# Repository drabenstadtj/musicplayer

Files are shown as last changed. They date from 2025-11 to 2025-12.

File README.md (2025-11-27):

# Raspberry Pi Portable Music Player

A portable music player built with Raspberry Pi Zero 2W that streams from Navidrome server with a 2.2" TFT display and I2S audio output.

## Hardware Components

- **Raspberry Pi Zero 2W** - Main computer
- **Adafruit PiTFT 2.2" HAT (320x240, no touch)** [ID:2315] - Display
- **Adafruit I2S Stereo Decoder - UDA1334A** [ID:3678] - DAC for audio output
- **PowerBoost 1000 Charger** [ID:2465] - Battery management and 5V boost
- **Lithium Ion Polymer Battery 3.7v 2500mAh** [ID:328] - Power source
- **Stacking Header 2x20 Extra Tall** [ID:1979] - For connecting HAT and components
- **Brass M2.5 Standoffs** [ID:2336] - Mounting hardware
- **4 tactile buttons** - User input (GPIO 17, 22, 23, 27)

## Hardware Connections

### I2S DAC (UDA1334A)
```
VIN  → 3.3V (pin 1)
GND  → Ground (pin 6)
WSEL → GPIO 19 (pin 35, I2S Frame Sync)
DIN  → GPIO 21 (pin 40, I2S Data)
BCLK → GPIO 18 (pin 12, I2S Bit Clock)
```

### PiTFT 2.2" Display
- Mounts directly on stacking header
- Uses SPI interface (automatically configured)

### PowerBoost 1000C
- Battery → JST connector on PowerBoost
- USB input → Micro USB on PowerBoost (for charging)
- 5V output → Pi GPIO pins 2 or 4 (5V) and pin 6 (GND)
- LBO pin → GPIO 4 (optional, for battery monitoring)

### Buttons (to be implemented)
```
BTN1 (Up)     → GPIO 17
BTN2 (Down)   → GPIO 22
BTN3 (Select) → GPIO 23
BTN4 (Back)   → GPIO 27
```

## Software Architecture

```
musicplayer/
├── main.py              # Entry point, curses setup
├── config.py            # Configuration (reads from .env)
├── .env                 # Credentials (NOT in git)
├── ui/
│   ├── screens.py       # Screen classes (Menu, Browser, NowPlaying)
│   ├── widgets.py       # Reusable UI components
│   └── theme.py         # Colors, fonts, layout constants
├── player/
│   ├── navidrome.py     # Navidrome API client
│   ├── audio.py         # Audio playback (pygame)
│   └── queue.py         # Playback queue (to be implemented)
├── hardware/
│   ├── buttons.py       # GPIO button handling (to be implemented)
│   └── battery.py       # Battery monitoring (to be implemented)
└── setup/
    ├── config_backups/  # Hardware config backups
    ├── restore_configs.sh
    ├── SETUP.md         # Detailed setup instructions
    └── REIMAGING_CHECKLIST.md
```

## Installation

### Quick Start (Pre-configured SD Card)

1. **Clone repository:**
   ```bash
   git clone git@github.com:YOUR_USERNAME/musicplayer.git
   cd musicplayer
   ```

2. **Restore hardware configuration:**
   ```bash
   sudo ./setup/restore_configs.sh
   sudo reboot
   ```

3. **Install dependencies:**
   ```bash
   python3 -m venv env --system-site-packages
   source env/bin/activate
   pip install -r requirements.txt
   ```

4. **Configure credentials:**
   ```bash
   cp .env.example .env
   nano .env
   # Add your Navidrome server URL, username, and password
   ```

5. **Run:**
   ```bash
   python main.py
   ```

### Fresh Installation (See setup/SETUP.md)

For complete step-by-step instructions on setting up from a fresh Raspberry Pi OS Lite image, see [setup/SETUP.md](setup/SETUP.md).

## Hardware Configuration Files

### `/boot/firmware/config.txt`
```bash
# I2S DAC
dtparam=audio=off
dtoverlay=hifiberry-dac

# PiTFT 2.2" Display
dtoverlay=pitft22,rotate=270,speed=64000000,fps=30
```

### `/boot/firmware/cmdline.txt`
Add to end of line:
```
fbcon=map:10 fbcon=font:VGA8x8
```

### `/etc/asound.conf`
ALSA configuration to route audio to I2S DAC (card 1). See `setup/config_backups/asound.conf`.

## Usage

### Current Features (Phase 3)
- ✅ Browse albums from Navidrome server
- ✅ Stream and play music through I2S DAC
- ✅ Volume control (↑/↓ arrows)
- ✅ Pause/play (Spacebar)
- ✅ Navigation with keyboard

### Keyboard Controls
```
Main Menu:
  ↑/↓        - Navigate menu
  ENTER      - Select option
  Q          - Quit

Album Browser:
  ↑/↓        - Navigate lists
  ENTER      - Select album / Play song
  BACKSPACE  - Go back
  Q          - Quit

Now Playing:
  SPACE      - Play / Pause
  ↑/↓        - Volume up / down
  BACKSPACE  - Return to browser
  Q          - Quit
```

## Planned Features (Future Phases)

### Phase 4: Hardware Integration
- [ ] GPIO button support (replace keyboard)
- [ ] Battery level monitoring
- [ ] Power management

### Phase 5: Advanced Features
- [ ] Playlist support
- [ ] Queue management
- [ ] Shuffle/repeat modes
- [ ] Album art display
- [ ] Settings menu

### Phase 6: Polish
- [ ] Auto-start on boot
- [ ] Sleep timer
- [ ] Display timeout/dimming
- [ ] Safe shutdown on low battery

## Development

### Requirements
- Python 3.9+
- pygame
- requests
- python-dotenv

### Environment Variables (.env)
```bash
NAVIDROME_URL=https://your-server.com
NAVIDROME_USER=username
NAVIDROME_PASS=password
```

### Testing Audio
```bash
# Test I2S DAC
speaker-test -c2 -t wav

# Check audio devices
aplay -l

# Should show:
# card 1: sndrpihifiberry [snd_rpi_hifiberry_dac]
```

### Testing Display
```bash
# Display should show console after boot
# Run music player to see ncurses interface
python main.py
```

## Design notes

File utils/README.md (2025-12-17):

# Music Player Logging System

This directory contains the centralized logging system for the Music Player application.

## Log Files

All logs are stored in `/tmp/musicplayer_logs/`:

- **musicplayer.log** - Main application logs (navigation, user actions)
- **audio.log** - Audio playback logs (VLC, PulseAudio, streaming details) [DEBUG level]
- **ui.log** - UI rendering and screen updates
- **hardware.log** - Button events and GPIO interactions
- **network.log** - Network requests to Navidrome server [DEBUG level]

## Log Rotation

Logs automatically rotate when they reach 5MB, keeping 3 backup files:
- `musicplayer.log` (current)
- `musicplayer.log.1` (previous)
- `musicplayer.log.2` (older)
- `musicplayer.log.3` (oldest)

## Usage

```python
from utils.logger import get_logger

logger = get_logger("main")  # or "audio", "ui", "hardware", "network"

logger.debug("Detailed debugging information")
logger.info("General information")
logger.warning("Warning messages")
logger.error("Error messages")
logger.exception("Error with full stack trace")
```

## Log Levels

- **DEBUG**: Detailed diagnostic information (VLC states, UI updates)
- **INFO**: General informational messages (navigation, playback events)
- **WARNING**: Warning messages (missing features, fallback behavior)
- **ERROR**: Error messages with stack traces

## Viewing Logs

On the Raspberry Pi:
```bash
# View real-time logs
tail -f /tmp/musicplayer_logs/musicplayer.log
tail -f /tmp/musicplayer_logs/audio.log

# View all logs
cat /tmp/musicplayer_logs/musicplayer.log

# Search logs
grep "ERROR" /tmp/musicplayer_logs/*.log
```

## Log Format

```
YYYY-MM-DD HH:MM:SS | logger_name | LEVEL | message
```

Example:
```
2025-01-15 14:23:45 | audio | INFO | ✓ VLC is now playing!
2025-01-15 14:23:46 | main | INFO | Navigating to Albums
```

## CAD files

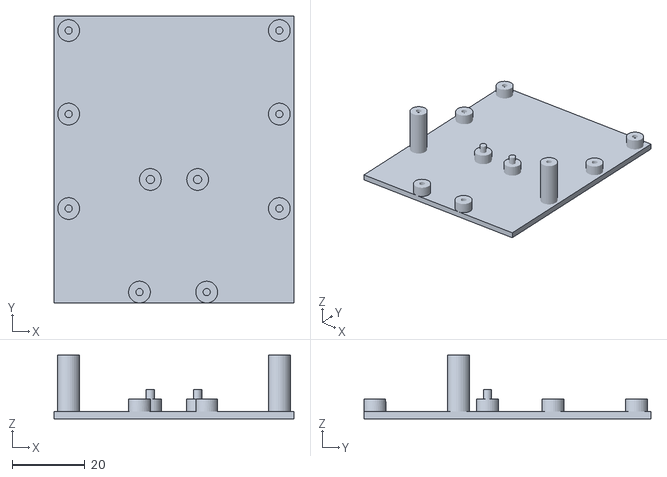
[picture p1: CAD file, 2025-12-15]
case/pi case v1.stl
66.0 x 79.0 x 17.5

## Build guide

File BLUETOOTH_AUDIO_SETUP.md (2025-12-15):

# Bluetooth-Only Audio Setup for Raspberry Pi

This guide configures your Raspberry Pi to use Bluetooth headphones as the only audio output (no sound card required).

## Prerequisites

```bash
# Update system
sudo apt-get update
sudo apt-get upgrade

# Install required packages
sudo apt-get install -y bluetooth bluez pulseaudio pulseaudio-module-bluetooth

# Install Python requirements
pip3 install -r requirements.txt
```

## PulseAudio Configuration

### 1. Enable PulseAudio for your user

```bash
# Start PulseAudio
pulseaudio --start

# Make it start automatically
systemctl --user enable pulseaudio
```

### 2. Configure PulseAudio for Bluetooth

Edit `/etc/pulse/default.pa` and ensure these lines are present:

```
# Bluetooth support
load-module module-bluetooth-policy
load-module module-bluetooth-discover
```

### 3. Restart PulseAudio

```bash
pulseaudio -k
pulseaudio --start
```

## Bluetooth Setup

### 1. Enable Bluetooth service

```bash
sudo systemctl enable bluetooth
sudo systemctl start bluetooth
```

### 2. Check Bluetooth is working

```bash
bluetoothctl
# Inside bluetoothctl:
power on
agent on
default-agent
scan on
# Wait for your headphones to appear, then:
scan off
exit
```

## Troubleshooting

### No audio output / ALSA errors

If you see ALSA errors like:
```
ALSA lib confmisc.c:855:(parse_card) cannot find card '0'
ALSA lib pcm.c:2722:(snd_pcm_open_noupdate) Unknown PCM default
```

This is normal when you don't have a sound card. The app now uses PulseAudio instead.

To verify PulseAudio is working:

```bash
# Check PulseAudio status
pulseaudio --check
echo $?  # Should return 0 if running

# List audio sinks (should show Bluetooth when connected)
pactl list short sinks

# Test audio (should work after connecting Bluetooth)
paplay /usr/share/sounds/alsa/Front_Center.wav
```

### Bluetooth scan finds 0 devices

1. **Make sure Bluetooth is enabled:**
   ```bash
   sudo systemctl status bluetooth
   # Should show "active (running)"
   ```

2. **Put your headphones in pairing mode:**
   - Most headphones require holding the power button for 5-10 seconds
   - Look for a flashing LED (usually blue/red alternating)

3. **Check permissions:**
   ```bash
   # Your user should be in the bluetooth group
   sudo usermod -a -G bluetooth $USER
   # Log out and back in for group change to take effect
   ```

4. **Manual scan test:**
   ```bash
   bluetoothctl
   power on
   scan on
   # Wait 10 seconds - you should see devices appear
   ```

5. **Check Bluetooth hardware:**
   ```bash
   hciconfig
   # Should show hci0 UP RUNNING

   # If not UP:
   sudo hciconfig hci0 up
   ```

### Connected but no audio

1. **Ensure Bluetooth is set as default sink:**
   ```bash
   # List sinks
   pactl list short sinks

   # Look for bluez_sink.XX_XX_XX_XX_XX_XX
   # Set as default (replace with your actual sink name):
   pactl set-default-sink bluez_sink.XX_XX_XX_XX_XX_XX.a2dp_sink
   ```

2. **Check audio routing:**
   ```bash
   # See active audio streams
   pactl list sink-inputs

   # Move to Bluetooth (replace IDs with actual values):
   pactl move-sink-input <INPUT_ID> bluez_sink.XX_XX_XX_XX_XX_XX.a2dp_sink
   ```

3. **Verify codec:**
   ```bash
   # Check Bluetooth audio profile
   pactl list cards
   # Look for "Active Profile: a2dp_sink" (high quality)
   # If showing "headset_head_unit" (low quality), change it:
   pactl set-card-profile bluez_card.XX_XX_XX_XX_XX_XX a2dp_sink
   ```

### App still shows "No audio available"

This means pygame couldn't initialize with PulseAudio. Check:

```bash
# Make sure PulseAudio is running
pulseaudio --check && echo "Running" || echo "Not running"

# Check if SDL can see PulseAudio
SDL_AUDIODRIVER=pulseaudio python3 -c "import pygame; pygame.mixer.init(); print('OK')"
```

If this fails, try:

```bash
# Restart PulseAudio
pulseaudio -k
pulseaudio --start

# Try the app again
python3 main.py
```

## Using the Music Player

Once Bluetooth is set up:

1. **Start the app:**
   ```bash
   cd ~/musicplayer  # or wherever you installed it
   python3 main.py
   ```

2. **Connect headphones:**
   - Navigate to Settings → Bluetooth Audio
   - Press SELECT on "Scan for devices"
   - Wait for scan to complete
   - Navigate to your headphones
   - Press SELECT to connect

3. **The app will automatically:**
   - Pair with the device (if needed)
   - Connect to it
   - Set it as the default audio sink
   - Route all music to your headphones

4. **Auto-reconnect:**
   - Once connected, the device is trusted
   - It will auto-reconnect when powered on in range

## PulseAudio + Bluetooth Architecture

```
┌─────────────────┐
│  Music Player   │
│   (pygame)      │
└────────┬────────┘
         │
         │ SDL_AUDIODRIVER=pulseaudio
         ▼
┌─────────────────┐
│  PulseAudio     │
│   (sound server)│
└────────┬────────┘
         │
         │ module-bluetooth-discover
         ▼
┌─────────────────┐
│  BlueZ          │
│   (Bluetooth)   │
└────────┬────────┘
         │
         │ A2DP profile
         ▼
┌─────────────────┐
│  Headphones     │
└─────────────────┘
```

The app bypasses ALSA entirely by:
1. Setting `SDL_AUDIODRIVER=pulseaudio` in [player/audio.py](player/audio.py:10)
2. PulseAudio handles all audio routing
3. When Bluetooth device connects, PulseAudio creates a `bluez_sink`
4. The app's BluetoothManager sets this as the default sink
5. All pygame audio automatically routes to Bluetooth

## Performance Tips

For best audio quality on Bluetooth:

1. **Disable WiFi power saving (can interfere with Bluetooth):**
   ```bash
   sudo iwconfig wlan0 power off
   ```

2. **Increase Bluetooth priority:**
   ```bash
   sudo nice -n -10 bluetoothd
   ```

3. **Use A2DP profile (not HSP/HFP):**
   - A2DP = high quality stereo
   - HSP/HFP = phone headset (mono, low quality)
   - The app automatically uses A2DP

4. **If you get choppy audio or static:**

   Edit `/etc/pulse/daemon.conf` and uncomment/set these values:
   ```
   default-fragment-size-msec = 25
   resample-method = soxr-vhq
   ```

   Then restart PulseAudio:
   ```bash
   pulseaudio -k
   pulseaudio --start
   ```

5. **Check WiFi interference:**
   - Both WiFi and Bluetooth use 2.4GHz band
   - If possible, use 5GHz WiFi or ethernet
   - Or disable WiFi: `sudo ifconfig wlan0 down`

## Common Issues

| Problem | Solution |
|---|---|
| Choppy audio / static | VLC buffer settings in [player/audio.py](player/audio.py:22), or tune PulseAudio (see Performance Tips #4) |
| Connection drops | Move Pi closer to headphones, reduce WiFi interference |
| Scan finds 0 devices | Headphones in pairing mode? Bluetooth service running? |
| No audio | Check PulseAudio running, Bluetooth connected, default sink set |
| ALSA errors | Normal - app uses PulseAudio not ALSA |

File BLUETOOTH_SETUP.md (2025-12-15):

# Bluetooth Audio Setup Guide

This guide explains how to use the Bluetooth settings screen to connect your Raspberry Pi to Bluetooth headphones.

## Prerequisites

On your Raspberry Pi, make sure you have the required packages:

```bash
sudo apt-get update
sudo apt-get install bluetooth bluez pulseaudio pulseaudio-module-bluetooth
```

## Using the Bluetooth Settings Screen

1. **Navigate to Settings**
   - From the main menu, select "Settings"
   - The Bluetooth Audio screen will open

2. **Scan for Devices**
   - Press `S` to scan for nearby Bluetooth devices
   - Scanning takes about 5 seconds
   - Your headphones should appear in the list

3. **Connect to Headphones**
   - Use ↑/↓ to navigate to your headphones
   - Press `ENTER` to connect
   - The app will:
     - Pair with the device (if not already paired)
     - Connect to the device
     - Set it as the default audio output
     - Trust the device for auto-reconnect

4. **Check Connection Status**
   - Connected devices show `[CONNECTED]` in green
   - Paired devices show `[PAIRED]` in yellow
   - The current connection is shown at the top

5. **Disconnect**
   - Press `D` to disconnect from the current device

## Keyboard Controls

- **↑/↓**: Navigate device list
- **ENTER**: Connect to selected device
- **S**: Scan for new devices
- **D**: Disconnect current device
- **BACKSPACE**: Return to main menu
- **Q**: Quit application

## Physical Button Controls

If using the hardware buttons:
- **UP/DOWN**: Navigate device list
- **SELECT**: Connect to selected device
- **BACK**: Return to main menu

## Troubleshooting

### Headphones not appearing
1. Make sure your headphones are in pairing mode
2. Press `S` to scan again
3. Make sure Bluetooth is enabled on the Pi: `sudo systemctl status bluetooth`

### Connection fails
1. Remove the device: Use `bluetoothctl` manually to remove
2. Restart Bluetooth service: `sudo systemctl restart bluetooth`
3. Try pairing again

### Audio still plays through Pi's output
The app automatically sets the Bluetooth device as the default audio sink. If this doesn't work:

```bash
# List audio sinks
pactl list short sinks

# Find the bluez sink and set as default
pactl set-default-sink bluez_sink.XX_XX_XX_XX_XX_XX.a2dp_sink
```

### Check audio routing
```bash
# See what's playing
pactl list sink-inputs

# Move audio to Bluetooth
pactl move-sink-input <input-id> bluez_sink.XX_XX_XX_XX_XX_XX.a2dp_sink
```

## Auto-reconnect

Once you've connected to a device, it's automatically trusted for auto-reconnect. Your headphones should reconnect automatically when:
- They're powered on
- They're in range
- Bluetooth is enabled on the Pi

## Technical Details

The Bluetooth manager uses:
- **bluetoothctl**: For device pairing and connection
- **PulseAudio (pactl)**: For audio routing

All audio played through pygame will automatically route to the connected Bluetooth device.

## Removing DAC Code

Since you removed the DAC hardware, the app now uses:
1. **Built-in audio** (if no Bluetooth connected)
2. **Bluetooth audio** (when connected via Settings)

The mock audio player is used if pygame can't initialize audio (like in WSL for development).

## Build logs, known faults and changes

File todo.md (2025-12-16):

TODO:
- cache album metadata from navidrome
- add album art display
- fix settings screen
- change scrolling to scroll album and artist together
- make arrows keep moving when holding down
- tune choppiness of playback
- fix volume control
- make album browser and album songlist separate screens
- make a way to get back to now playing screen (maybe button 1 and button 4 simultaneously)
- remove battery icon from now playing screen

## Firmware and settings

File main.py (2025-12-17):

import curses
from player.navidrome import NavidromeClient
from ui.screens import (MainMenuScreen, AlbumBrowserScreen, SongListScreen, NowPlayingScreen,
                        BluetoothSettingsScreen, ArtistBrowserScreen, PlaylistBrowserScreen)
from ui.theme import init_colors
from hardware.button_controller import ButtonController
from utils.logger import get_logger, log_startup, log_shutdown

logger = get_logger("main")

class MusicPlayerApp:
    def __init__(self, stdscr):
        logger.info("Initializing MusicPlayerApp")
        self.stdscr = stdscr

        # Try to connect to Navidrome
        logger.info("Connecting to Navidrome client")
        self.client = NavidromeClient()

        # Try to initialize audio player, fall back to mock if no audio device
        try:
            logger.info("Initializing audio player")
            from player.audio import AudioPlayer
            self.audio = AudioPlayer()
        except Exception as e:
            logger.warning(f"Failed to initialize audio player, using mock: {e}")
            from player.audio_mock import AudioPlayer
            self.audio = AudioPlayer()

        # Setup curses
        logger.debug("Setting up curses interface")
        curses.curs_set(0)
        self.stdscr.nodelay(1)
        self.stdscr.timeout(100)
        init_colors()

        self.current_screen = None
        self.running = True

        # Cache for metadata
        self.cached_albums = None
        self.cached_artists = None
        self.cached_playlists = None

        # Track if now playing screen is available
        self.has_active_playback = False
        self.should_return_to_now_playing = False

        # Initialize button controller
        logger.info("Initializing button controller")
        self.button_controller = ButtonController(self, use_gpio=True)
        self.button_controller.start()
        logger.info("MusicPlayerApp initialization complete")
    
    def run(self):
        logger.info("Starting main application loop")
        # Test Navidrome connection
        if not self.client.test_connection():
            logger.error("Failed to connect to Navidrome server")
            self.stdscr.clear()
            self.stdscr.addstr(0, 0, "Failed to connect to Navidrome server!")
            self.stdscr.addstr(1, 0, "Press any key to exit...")
            self.stdscr.refresh()
            self.stdscr.getch()
            return

        logger.info("Navidrome connection successful")
        # Start with main menu
        try:
            while self.running:
                menu = MainMenuScreen(self.stdscr)
                self.current_screen = menu
                menu.draw()
                
                while self.running:
                    key = self.stdscr.getch()

                    result = None

                    if key != -1:
                        # Try button emulator first, only call handle_input if not handled
                        handled_by_buttons = self._handle_keyboard_input(key)
                        if not handled_by_buttons:
                            result = menu.handle_input(key)
                    
                    # Check for button actions
                    if hasattr(menu, '_pending_action') and menu._pending_action:
                        result = menu._pending_action
                        menu._pending_action = None
                    
                    if result == False:
                        logger.info("User quit from main menu")
                        self.running = False
                        break
                    elif result == "Albums":
                        logger.info("Navigating to Albums")
                        self.show_albums()
                        break
                    elif result == "Artists":
                        logger.info("Navigating to Artists")
                        self.show_artists()
                        break
                    elif result == "Playlists":
                        logger.info("Navigating to Playlists")
                        self.show_playlists()
                        break
                    elif result == "Settings":
                        logger.info("Navigating to Settings")
                        self.show_settings()
                        break
                    elif result:
                        menu.draw()
        finally:
            logger.info("Application shutting down")
            self.cleanup()
    
    def _handle_keyboard_input(self, key):
        """Handle keyboard input via button emulator

        Returns:
            True if key was handled by button emulator, False otherwise
        """
        from hardware.buttons import KeyboardButtonEmulator

        if isinstance(self.button_controller.handler, KeyboardButtonEmulator):
            key_map = {
                curses.KEY_UP: 'KEY_UP',
                curses.KEY_DOWN: 'KEY_DOWN',
                curses.KEY_BACKSPACE: 'KEY_BACKSPACE',
                127: 'KEY_BACKSPACE',
                10: '\n',
            }

            mapped_key = key_map.get(key)
            if mapped_key:
                self.button_controller.handler.handle_key(mapped_key)
                return True
        return False
    
    def show_albums(self):
        # Use cached albums if available, otherwise fetch from Navidrome
        if self.cached_albums is None:
            logger.info("Fetching albums from Navidrome")
            albums = self.client.get_all_albums()
            self.cached_albums = albums
            logger.info(f"Cached {len(albums)} albums")
        else:
            logger.debug("Using cached albums")
            albums = self.cached_albums

        if not albums:
            logger.warning("No albums found")
            return

        browser = AlbumBrowserScreen(self.stdscr, albums)
        self.current_screen = browser
        browser.draw()

        while self.running:
            # Check for now playing combo
            if self.should_return_to_now_playing:
                self.should_return_to_now_playing = False
                self.show_now_playing()
                # Restore current_screen to browser after returning
                self.current_screen = browser
                browser.draw()
                continue

            key = self.stdscr.getch()

            result = None

            if key != -1:
                # Try button emulator first, only call handle_input if not handled
                handled_by_buttons = self._handle_keyboard_input(key)
                if not handled_by_buttons:
                    result = browser.handle_input(key)

            # Check for button actions
            if hasattr(browser, '_pending_action') and browser._pending_action:
                result = browser._pending_action
                browser._pending_action = None

            if result == False or result == "back":
                logger.info("Returning to main menu from albums")
                break
            elif isinstance(result, tuple):
                action, data = result
                if action == "select_album":
                    logger.info(f"Album selected: {data.get('name', 'Unknown')}")
                    # Show song list screen (this will return when user presses back)
                    self.show_song_list(data)
                    # Restore current_screen to browser after returning from song list
                    self.current_screen = browser
                    browser.draw()

            browser.draw()

    def show_song_list(self, album):
        """Show song list for an album"""
        logger.info(f"Loading songs for album: {album.get('name', 'Unknown')}")
        # Load songs from Navidrome
        songs = self.client.get_album_songs(album['id'])

        if not songs:
            logger.warning(f"No songs found for album: {album.get('name', 'Unknown')}")
            return

        logger.info(f"Loaded {len(songs)} songs")

        song_list = SongListScreen(self.stdscr, album, songs)
        self.current_screen = song_list
        song_list.draw()

        while self.running:
            # Check for now playing combo
            if self.should_return_to_now_playing:
                self.should_return_to_now_playing = False
                self.show_now_playing()
                # Restore current_screen to song_list after returning
                self.current_screen = song_list
                song_list.draw()
                continue

            key = self.stdscr.getch()

            result = None

            if key != -1:
                # Try button emulator first, only call handle_input if not handled
                handled_by_buttons = self._handle_keyboard_input(key)
                if not handled_by_buttons:
                    result = song_list.handle_input(key)

            # Check for button actions
            if hasattr(song_list, '_pending_action') and song_list._pending_action:
                result = song_list._pending_action
                song_list._pending_action = None

            if result == False:
                logger.info("Exiting song list (returning to album browser)")
                return  # Return to album browser
            elif result == "back":
                logger.info("Back pressed in song list")
                return  # Return to album browser
            elif isinstance(result, tuple):
                action, data = result
                if action == "play_song":
                    logger.info(f"Playing song: {data.get('title', 'Unknown')}")
                    self.play_song(data)
                    self.show_now_playing()
                    # Restore current_screen to song_list after returning
                    self.current_screen = song_list
                    song_list.draw()

            song_list.draw()

    def play_song(self, song):
        """Start playing a song"""
        logger.info(f"Requesting stream for song: {song.get('title', 'Unknown')} by {song.get('artist', 'Unknown')}")
        stream_url = self.client.get_stream_url(song['id'])
        if stream_url:
            logger.info(f"Stream URL obtained: {stream_url}")
            self.audio.play(stream_url, song)
            self.has_active_playback = True
        else:
            logger.error(f"Failed to get stream URL for song: {song.get('title', 'Unknown')}")

    def show_now_playing(self):
        """Show now playing screen"""
        logger.info("Showing now playing screen")
        now_playing = NowPlayingScreen(self.stdscr, self.audio, self.client)
        self.current_screen = now_playing
        now_playing.draw()

        while self.running:
            key = self.stdscr.getch()

            result = None

            if key != -1:
                # Try button emulator first, only call handle_input if not handled
                handled_by_buttons = self._handle_keyboard_input(key)
                if not handled_by_buttons:
                    result = now_playing.handle_input(key)

            # Check for button actions
            if hasattr(now_playing, '_pending_action') and now_playing._pending_action:
                result = now_playing._pending_action
                now_playing._pending_action = None

            if result == False:
                logger.info("Exiting now playing screen")
                return  # Exit and return to previous screen
            elif result == "back":
                logger.info("Back pressed in now playing screen")
                return  # Exit and return to previous screen

            now_playing.draw()

    def show_settings(self):
        """Show settings menu"""
        logger.info("Showing settings screen")
        bt_settings = BluetoothSettingsScreen(self.stdscr)
        self.current_screen = bt_settings
        bt_settings.draw()

        while self.running:
            # Check for now playing combo
            if self.should_return_to_now_playing:
                self.should_return_to_now_playing = False
                self.show_now_playing()
                # Restore current_screen to bt_settings after returning
                self.current_screen = bt_settings
                bt_settings.draw()
                continue

            key = self.stdscr.getch()

            result = None

            if key != -1:
                # Try button emulator first, only call handle_input if not handled
                handled_by_buttons = self._handle_keyboard_input(key)
                if not handled_by_buttons:
                    result = bt_settings.handle_input(key)

            # Check for button actions
            if hasattr(bt_settings, '_pending_action') and bt_settings._pending_action:
                result = bt_settings._pending_action
                bt_settings._pending_action = None

            if result == False or result == "back":
                logger.info("Exiting settings screen")
                break

            bt_settings.draw()

    def show_artists(self):
        """Show artists browser"""
        # Use cached artists if available, otherwise fetch from Navidrome
        if self.cached_artists is None:
            logger.info("Fetching artists from Navidrome")
            artists = self.client.get_artists()
            self.cached_artists = artists
            logger.info(f"Cached {len(artists)} artists")
        else:
            logger.debug("Using cached artists")
            artists = self.cached_artists

        if not artists:
            logger.warning("No artists found")
            return

        browser = ArtistBrowserScreen(self.stdscr, artists)
        self.current_screen = browser
        browser.draw()

        while self.running:
            # Check for now playing combo
            if self.should_return_to_now_playing:
                self.should_return_to_now_playing = False
                self.show_now_playing()
                self.current_screen = browser
                browser.draw()
                continue

            key = self.stdscr.getch()

            result = None

            if key != -1:
                # Try button emulator first, only call handle_input if not handled
                handled_by_buttons = self._handle_keyboard_input(key)
                if not handled_by_buttons:
                    result = browser.handle_input(key)

            # Check for button actions
            if hasattr(browser, '_pending_action') and browser._pending_action:
                result = browser._pending_action
                browser._pending_action = None

            if result == False or result == "back":
                logger.info("Returning to main menu from artists")
                break
            elif isinstance(result, tuple):
                action, data = result
                if action == "select_artist":
                    logger.info(f"Artist selected: {data.get('name', 'Unknown')}")
                    # Show artist's albums
                    self.show_artist_albums(data)
                    # Restore current_screen to browser after returning
                    self.current_screen = browser
                    browser.draw()

            browser.draw()

    def show_artist_albums(self, artist):
        """Show albums for a specific artist"""
        logger.info(f"Loading albums for artist: {artist.get('name', 'Unknown')}")
        albums = self.client.get_artist_albums(artist['id'])

        if not albums:
            logger.warning(f"No albums found for artist: {artist.get('name', 'Unknown')}")
            return

        logger.info(f"Loaded {len(albums)} albums")

        # Create album browser for this artist's albums
        browser = AlbumBrowserScreen(self.stdscr, albums)
        self.current_screen = browser
        browser.draw()

        while self.running:
            # Check for now playing combo
            if self.should_return_to_now_playing:
                self.should_return_to_now_playing = False
                self.show_now_playing()
                self.current_screen = browser
                browser.draw()
                continue

            key = self.stdscr.getch()

            result = None

            if key != -1:
                # Try button emulator first, only call handle_input if not handled
                handled_by_buttons = self._handle_keyboard_input(key)
                if not handled_by_buttons:
                    result = browser.handle_input(key)

            # Check for button actions
            if hasattr(browser, '_pending_action') and browser._pending_action:
                result = browser._pending_action
                browser._pending_action = None

            if result == False or result == "back":
                logger.info("Returning to artist browser from albums")
                return  # Return to artist browser
            elif isinstance(result, tuple):
                action, data = result
                if action == "select_album":
                    logger.info(f"Album selected: {data.get('name', 'Unknown')}")
                    # Show song list screen
                    self.show_song_list(data)
                    # Restore current_screen to browser after returning from song list
                    self.current_screen = browser
                    browser.draw()

            browser.draw()

    def show_playlists(self):
        """Show playlists browser"""
        # Use cached playlists if available, otherwise fetch from Navidrome
        if self.cached_playlists is None:
            logger.info("Fetching playlists from Navidrome")
            playlists = self.client.get_playlists()
            self.cached_playlists = playlists
            logger.info(f"Cached {len(playlists)} playlists")
        else:
            logger.debug("Using cached playlists")
            playlists = self.cached_playlists

        if not playlists:
            logger.warning("No playlists found")
            return

        browser = PlaylistBrowserScreen(self.stdscr, playlists)
        self.current_screen = browser
        browser.draw()

        while self.running:
            # Check for now playing combo
            if self.should_return_to_now_playing:
                self.should_return_to_now_playing = False
                self.show_now_playing()
                self.current_screen = browser
                browser.draw()
                continue

            key = self.stdscr.getch()

            result = None

            if key != -1:
                # Try button emulator first, only call handle_input if not handled
                handled_by_buttons = self._handle_keyboard_input(key)
                if not handled_by_buttons:
                    result = browser.handle_input(key)

            # Check for button actions
            if hasattr(browser, '_pending_action') and browser._pending_action:
                result = browser._pending_action
                browser._pending_action = None

            if result == False or result == "back":
                logger.info("Returning to main menu from playlists")
                break
            elif isinstance(result, tuple):
                action, data = result
                if action == "select_playlist":
                    logger.info(f"Playlist selected: {data.get('name', 'Unknown')}")
                    # Show playlist songs
                    self.show_playlist_songs(data)
                    # Restore current_screen to browser after returning
                    self.current_screen = browser
                    browser.draw()

            browser.draw()

    def show_playlist_songs(self, playlist):
        """Show songs in a playlist"""
        logger.info(f"Loading songs for playlist: {playlist.get('name', 'Unknown')}")
        songs = self.client.get_playlist_songs(playlist['id'])

        if not songs:
            logger.warning(f"No songs found in playlist: {playlist.get('name', 'Unknown')}")
            return

        logger.info(f"Loaded {len(songs)} songs")

        # Create song list screen for playlist
        song_list = SongListScreen(self.stdscr, playlist, songs)
        self.current_screen = song_list
        song_list.draw()

        while self.running:
            # Check for now playing combo
            if self.should_return_to_now_playing:
                self.should_return_to_now_playing = False
                self.show_now_playing()
                self.current_screen = song_list
                song_list.draw()
                continue

            key = self.stdscr.getch()

            result = None

            if key != -1:
                # Try button emulator first, only call handle_input if not handled
                handled_by_buttons = self._handle_keyboard_input(key)
                if not handled_by_buttons:
                    result = song_list.handle_input(key)

            # Check for button actions
            if hasattr(song_list, '_pending_action') and song_list._pending_action:
                result = song_list._pending_action
                song_list._pending_action = None

            if result == False:
                logger.info("Exiting playlist songs (returning to playlist browser)")
                return  # Return to playlist browser
            elif result == "back":
                logger.info("Back pressed in playlist songs")
                return  # Return to playlist browser
            elif isinstance(result, tuple):
                action, data = result
                if action == "play_song":
                    logger.info(f"Playing song: {data.get('title', 'Unknown')}")
                    self.play_song(data)
                    self.show_now_playing()
                    # Restore current_screen to song_list after returning
                    self.current_screen = song_list
                    song_list.draw()

            song_list.draw()

    def quit(self):
        logger.info("Quit requested")
        self.running = False
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

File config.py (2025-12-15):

import os
from dotenv import load_dotenv

# Load environment variables from .env file
load_dotenv()

# Navidrome server configuration
NAVIDROME_URL = os.getenv("NAVIDROME_URL", "https://listen.wintermute.lol")
NAVIDROME_USER = os.getenv("NAVIDROME_USER", "jack")
NAVIDROME_PASS = os.getenv("NAVIDROME_PASS", "")

# Display settings
SCREEN_WIDTH = 320
SCREEN_HEIGHT = 240

# UI Layout (in pixels)
STATUS_BAR_HEIGHT = 20
FOOTER_HEIGHT = 20
CONTENT_HEIGHT = SCREEN_HEIGHT - STATUS_BAR_HEIGHT - FOOTER_HEIGHT

# Split view widths
LEFT_PANEL_WIDTH = 160
RIGHT_PANEL_WIDTH = 160

# Now Playing layout
ALBUM_ART_SIZE = 180
PROGRESS_BAR_HEIGHT = 30

# Colors (curses color pair numbers)
COLOR_NORMAL = 1
COLOR_SELECTED = 2
COLOR_STATUS = 3
COLOR_PROGRESS = 4

# Button GPIO pins
BTN_UP = 17
BTN_DOWN = 22
BTN_SELECT = 23
BTN_BACK = 27

# Battery monitoring
LBO_PIN = 4  # PowerBoost Low Battery Output

# Playback settings
DEFAULT_VOLUME = 70
BUFFER_SIZE = 8192

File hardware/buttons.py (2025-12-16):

"""
GPIO Button Handler for Music Player
Handles 4 tactile buttons with debouncing and event callbacks
"""

import time
from enum import Enum
from typing import Callable, Dict, Optional
import threading

try:
    import RPi.GPIO as GPIO
    GPIO_AVAILABLE = True
except (ImportError, RuntimeError):
    GPIO_AVAILABLE = False
    print("RPi.GPIO not available - button support disabled")


class Button(Enum):
    """Button definitions matching hardware GPIO pins"""
    UP = 17      # BTN1 - Navigate up
    DOWN = 22    # BTN2 - Navigate down
    SELECT = 23  # BTN3 - Select/Confirm
    BACK = 27    # BTN4 - Back/Cancel


class ButtonEvent(Enum):
    """Types of button events"""
    PRESS = "press"           # Button just pressed
    RELEASE = "release"       # Button just released
    LONG_PRESS = "long_press" # Button held for >1 second
    DOUBLE_PRESS = "double_press"  # Button pressed twice quickly


class ButtonHandler:
    """
    Manages GPIO buttons with debouncing and event callbacks.
    
    Usage:
        handler = ButtonHandler()
        handler.on_button(Button.SELECT, ButtonEvent.PRESS, lambda: print("Select!"))
        handler.start()
        # ... do other work ...
        handler.stop()
    """
    
    def __init__(self, debounce_time: float = 0.05, long_press_time: float = 1.0,
                 double_press_time: float = 0.3, repeat_delay: float = 0.5, repeat_interval: float = 0.15):
        """
        Initialize button handler.

        Args:
            debounce_time: Minimum time between button state changes (seconds)
            long_press_time: Time to hold for long press event (seconds)
            double_press_time: Max time between presses for double press (seconds)
            repeat_delay: Time before repeat starts when button held (seconds)
            repeat_interval: Time between repeat events (seconds)
        """
        self.debounce_time = debounce_time
        self.long_press_time = long_press_time
        self.double_press_time = double_press_time
        self.repeat_delay = repeat_delay
        self.repeat_interval = repeat_interval
        
        self._callbacks: Dict[Button, Dict[ButtonEvent, list]] = {
            button: {event: [] for event in ButtonEvent}
            for button in Button
        }
        
        self._button_states: Dict[Button, bool] = {button: False for button in Button}
        self._last_press_time: Dict[Button, float] = {button: 0 for button in Button}
        self._last_release_time: Dict[Button, float] = {button: 0 for button in Button}
        self._press_count: Dict[Button, int] = {button: 0 for button in Button}
        self._last_repeat_time: Dict[Button, float] = {button: 0 for button in Button}
        
        self._running = False
        self._monitor_thread: Optional[threading.Thread] = None
        
        if GPIO_AVAILABLE:
            self._setup_gpio()
    
    def _setup_gpio(self):
        """Configure GPIO pins for buttons"""
        GPIO.setmode(GPIO.BCM)
        GPIO.setwarnings(False)
        
        for button in Button:
            # Use pull-up resistor, button connects to ground
            GPIO.setup(button.value, GPIO.IN, pull_up_down=GPIO.PUD_UP)
            print(f"Configured {button.name} on GPIO {button.value}")
    
    def on_button(self, button: Button, event: ButtonEvent, callback: Callable):
        """
        Register a callback for a button event.
        
        Args:
            button: Which button to listen for
            event: What type of event to listen for
            callback: Function to call when event occurs (no arguments)
        """
        self._callbacks[button][event].append(callback)
    
    def remove_callback(self, button: Button, event: ButtonEvent, callback: Callable):
        """Remove a previously registered callback"""
        if callback in self._callbacks[button][event]:
            self._callbacks[button][event].remove(callback)
    
    def _trigger_callbacks(self, button: Button, event: ButtonEvent):
        """Execute all callbacks registered for this button/event combination"""
        for callback in self._callbacks[button][event]:
            try:
                callback()
            except Exception as e:
                print(f"Error in button callback: {e}")
    
    def _is_pressed(self, button: Button) -> bool:
        """Check if button is currently pressed (LOW = pressed with pull-up)"""
        if not GPIO_AVAILABLE:
            return False
        return GPIO.input(button.value) == GPIO.LOW
    
    def _monitor_buttons(self):
        """Main monitoring loop - runs in background thread"""
        while self._running:
            current_time = time.time()
            
            for button in Button:
                is_pressed = self._is_pressed(button)
                was_pressed = self._button_states[button]
                
                # State change detected
                if is_pressed != was_pressed:
                    # Debounce check
                    if is_pressed:
                        # Button press
                        time_since_last_press = current_time - self._last_press_time[button]
                        
                        if time_since_last_press >= self.debounce_time:
                            self._button_states[button] = True
                            self._last_press_time[button] = current_time
                            
                            # Check for double press
                            time_since_last_release = current_time - self._last_release_time[button]
                            if time_since_last_release < self.double_press_time:
                                self._press_count[button] += 1
                                if self._press_count[button] == 2:
                                    self._trigger_callbacks(button, ButtonEvent.DOUBLE_PRESS)
                                    self._press_count[button] = 0
                            else:
                                self._press_count[button] = 1
                            
                            # Trigger press event
                            self._trigger_callbacks(button, ButtonEvent.PRESS)
                    else:
                        # Button release
                        time_since_last_release = current_time - self._last_release_time[button]
                        
                        if time_since_last_release >= self.debounce_time:
                            self._button_states[button] = False
                            self._last_release_time[button] = current_time
                            
                            # Trigger release event
                            self._trigger_callbacks(button, ButtonEvent.RELEASE)
                
                # Check for long press and auto-repeat
                elif is_pressed:
                    time_held = current_time - self._last_press_time[button]
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

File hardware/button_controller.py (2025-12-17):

"""
Button-to-UI Integration
Connects hardware buttons to UI navigation and player controls
"""

from hardware.buttons import Button, ButtonEvent, get_button_handler
from utils.logger import get_logger

logger = get_logger("hardware")


class ButtonController:
    """
    Maps button events to UI actions based on current screen/state.
    Acts as the glue between hardware buttons and UI screens.
    """
    
    def __init__(self, app, use_gpio=True):
        """
        Initialize button controller.

        Args:
            app: Main application instance with current_screen
            use_gpio: Whether to use GPIO or keyboard fallback
        """
        self.app = app
        self.handler = get_button_handler(use_gpio=use_gpio)
        self.button_states = {Button.UP: False, Button.DOWN: False, Button.SELECT: False, Button.BACK: False}
        self._setup_bindings()
    
    def _setup_bindings(self):
        """Register button event handlers"""
        # UP button - navigate up in lists
        self.handler.on_button(Button.UP, ButtonEvent.PRESS, self._on_up)
        self.handler.on_button(Button.UP, ButtonEvent.RELEASE, lambda: self._on_release(Button.UP))

        # DOWN button - navigate down in lists
        self.handler.on_button(Button.DOWN, ButtonEvent.PRESS, self._on_down)
        self.handler.on_button(Button.DOWN, ButtonEvent.RELEASE, lambda: self._on_release(Button.DOWN))

        # SELECT button - confirm/play
        self.handler.on_button(Button.SELECT, ButtonEvent.PRESS, self._on_select)
        self.handler.on_button(Button.SELECT, ButtonEvent.RELEASE, lambda: self._on_release(Button.SELECT))

        # BACK button - go back/cancel
        self.handler.on_button(Button.BACK, ButtonEvent.PRESS, self._on_back)
        self.handler.on_button(Button.BACK, ButtonEvent.RELEASE, lambda: self._on_release(Button.BACK))
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

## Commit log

2025-11-27 config backups
    [config.txt]
2025-12-15 fuckin temp
    [pi case v1.stl]
2025-12-15 removed ueberzeueg
    [config.txt]
2025-12-17 fix artists category skip
    [button_controller.py, screens.py]
